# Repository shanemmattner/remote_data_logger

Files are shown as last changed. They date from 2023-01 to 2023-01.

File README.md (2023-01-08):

# Remote Data Logger
Remote data logger project for use in engineering development and debugging of electronics in the field

## Feature List

### Hardware
- ESP32-C3 circuit
- uart connection to target
- uSD card
- 16 GPIO

### Firmware
- ADC reading
- UART read/write
- Store values to uSD card
- Send values via WiFi

### Software
- Graph readings from ESP32-C3
- Talk with ESP32-C3 through Wi-Fi
- Talk with ESP32-C3 through UART

## Git
Update submodules manually:
```
git submodule update  --init --recursive
```

Configure repo to use custom `.githooks` path and make files executable:
```
git config --local core.hooksPath .githooks/
chmod -R +x .githooks
```

## KiCAD Hotkeys
- `e` while routing:  change parameters of trace
- `b` re-pour copper fills
    - `ctrl + b` to remove all fills
- `u` select entire track
- `v` via when routing
    - switch to bottom when not routing
- `c` Design rule check panel
    - custom hotkey

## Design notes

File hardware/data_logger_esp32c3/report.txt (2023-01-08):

Plotted to '/home/shane/Desktop/remote_data_logger/hardware/data_logger_esp32c3/gerbers/data_logger_esp32c3-F_Cu.gbr'.
Plotted to '/home/shane/Desktop/remote_data_logger/hardware/data_logger_esp32c3/gerbers/data_logger_esp32c3-In1_Cu.gbr'.
Plotted to '/home/shane/Desktop/remote_data_logger/hardware/data_logger_esp32c3/gerbers/data_logger_esp32c3-In2_Cu.gbr'.
Plotted to '/home/shane/Desktop/remote_data_logger/hardware/data_logger_esp32c3/gerbers/data_logger_esp32c3-B_Cu.gbr'.
Plotted to '/home/shane/Desktop/remote_data_logger/hardware/data_logger_esp32c3/gerbers/data_logger_esp32c3-F_Paste.gbr'.
Plotted to '/home/shane/Desktop/remote_data_logger/hardware/data_logger_esp32c3/gerbers/data_logger_esp32c3-B_Paste.gbr'.
Plotted to '/home/shane/Desktop/remote_data_logger/hardware/data_logger_esp32c3/gerbers/data_logger_esp32c3-F_Silkscreen.gbr'.
Plotted to '/home/shane/Desktop/remote_data_logger/hardware/data_logger_esp32c3/gerbers/data_logger_esp32c3-B_Silkscreen.gbr'.
Plotted to '/home/shane/Desktop/remote_data_logger/hardware/data_logger_esp32c3/gerbers/data_logger_esp32c3-F_Mask.gbr'.
Plotted to '/home/shane/Desktop/remote_data_logger/hardware/data_logger_esp32c3/gerbers/data_logger_esp32c3-B_Mask.gbr'.
Plotted to '/home/shane/Desktop/remote_data_logger/hardware/data_logger_esp32c3/gerbers/data_logger_esp32c3-Edge_Cuts.gbr'.
Created Gerber job file '/home/shane/Desktop/remote_data_logger/hardware/data_logger_esp32c3/gerbers/data_logger_esp32c3-job.gbrjob'.
Info: Done.

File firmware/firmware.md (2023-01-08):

# Firmware

Document to track firmware development

## Steps to set up a new ESP32 Rust project
1. [Install](https://github.com/esp-rs/rust-build) Rust and Xtensa build tools
    - Make sure to `sudo chmod +x export-esp.sh`
2. Start a project using the [esp-idf-template](https://github.com/esp-rs/esp-idf-template) from the private repo home `dir`. I chose all the default options
```
cargo generate --vcs none --git https://github.com/esp-rs/esp-idf-template cargo
```
3. Build the `Hello World` program by running `cargo build` in the new project dir. This will take a while to build the first time:
```
cd esp32-rust
cargo build
...
Finished dev [optimized + debuginfo] target(s) in 6m 40s
```
4. Flash the ESP32 with the build artifact:
```
espflash /dev/ttyACM0 target/riscv32imc-esp-espidf/debug/remote-data-logger
```
5. Connect to ESP32 and monitor
```
espmonitor /dev/ttyACM0
```

## TODO
- `Panic` if `pin 18/19` is reconfigured.  These pins are needed to download to the ESP32-C3 per [this](https://docs.espressif.com/projects/esp-idf/en/latest/esp32c3/api-guides/usb-serial-jtag-console.html) document

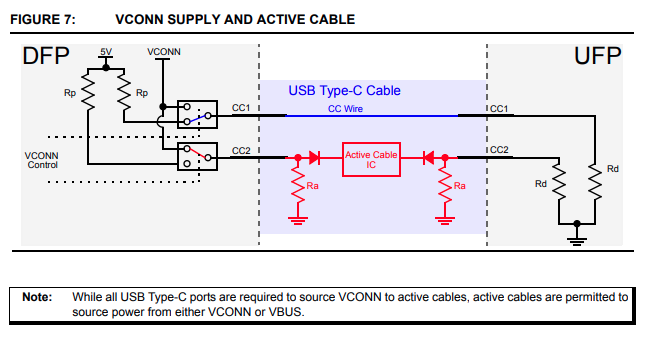
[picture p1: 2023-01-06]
pics/usbc_cc_pins.png

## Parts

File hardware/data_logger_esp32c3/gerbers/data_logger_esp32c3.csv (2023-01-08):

Id | Designator | Package | Quantity | Designation | Supplier and ref
1 | R18,R17 | R_0402_1005Metric | 2 | 30.1
2 | SDA1,SCL1,I2SP1,I2SN1,A4P1,A4N1,A3P1,A3N1,A2P1,A2N1,A0P1,A0N1,NRESET1,NINT1,IO13,DC-1,DC+1,IO11,IO5,VIN1,IO15,TX0,IO0,IO1,3V3,IO6,IO3,RX0,IO10,IO9,IO8,IO2,IO4,IO14,IO7,IO12 | TestPoint_THTPad_1.0x1.0mm_Drill0.5mm | 36 | TestPoint
3 | U5,U4,U8,U6,U7 | LM321MF | 5 | LM321MF
4 | R4,R1,R15,R3,R14,R9 | R_0402_1005Metric | 6 | 10k
5 | C1 | C_0402_1005Metric | 1 | 1uF
6 | R2,R7 | R_0402_1005Metric | 2 | 5.1k
7 | C2,C5,C4 | C_0603_1608Metric | 3 | 10uF
8 | SD1 | 472192001 | 1 | 472192001
9 | R12 | R_0402_1005Metric | 1 | 7.5k
10 | R6,R5,R13 | R_0402_1005Metric | 3 | 1k
11 | R16,R8 | R_0402_1005Metric | 2 | 4.7k
12 | U1 | ESP32-C3-MINI-1 | 1 | ESP32-C3-MINI-1
13 | R11 | R_0402_1005Metric | 1 | 3.92k
14 | R10 | R_0402_1005Metric | 1 | 1.6k
15 | U9,U10 | SOT-23 | 2 | A03401A
16 | D1 | DFN1610 | 1 | LTVS16H5.0T5G
17 | U2 | SOT-223-4 | 1 | AZ1117IH-3.3TRG1
18 | U11 | QFN-28-EP(4x4) | 1 | SX1509BIULTRT
19 | C3,C7,C6 | C_0402_1005Metric | 3 | 0.1uF
20 | USB-C1 | USB-TYPE-C-018 | 1 | USB-TYPE-C-018

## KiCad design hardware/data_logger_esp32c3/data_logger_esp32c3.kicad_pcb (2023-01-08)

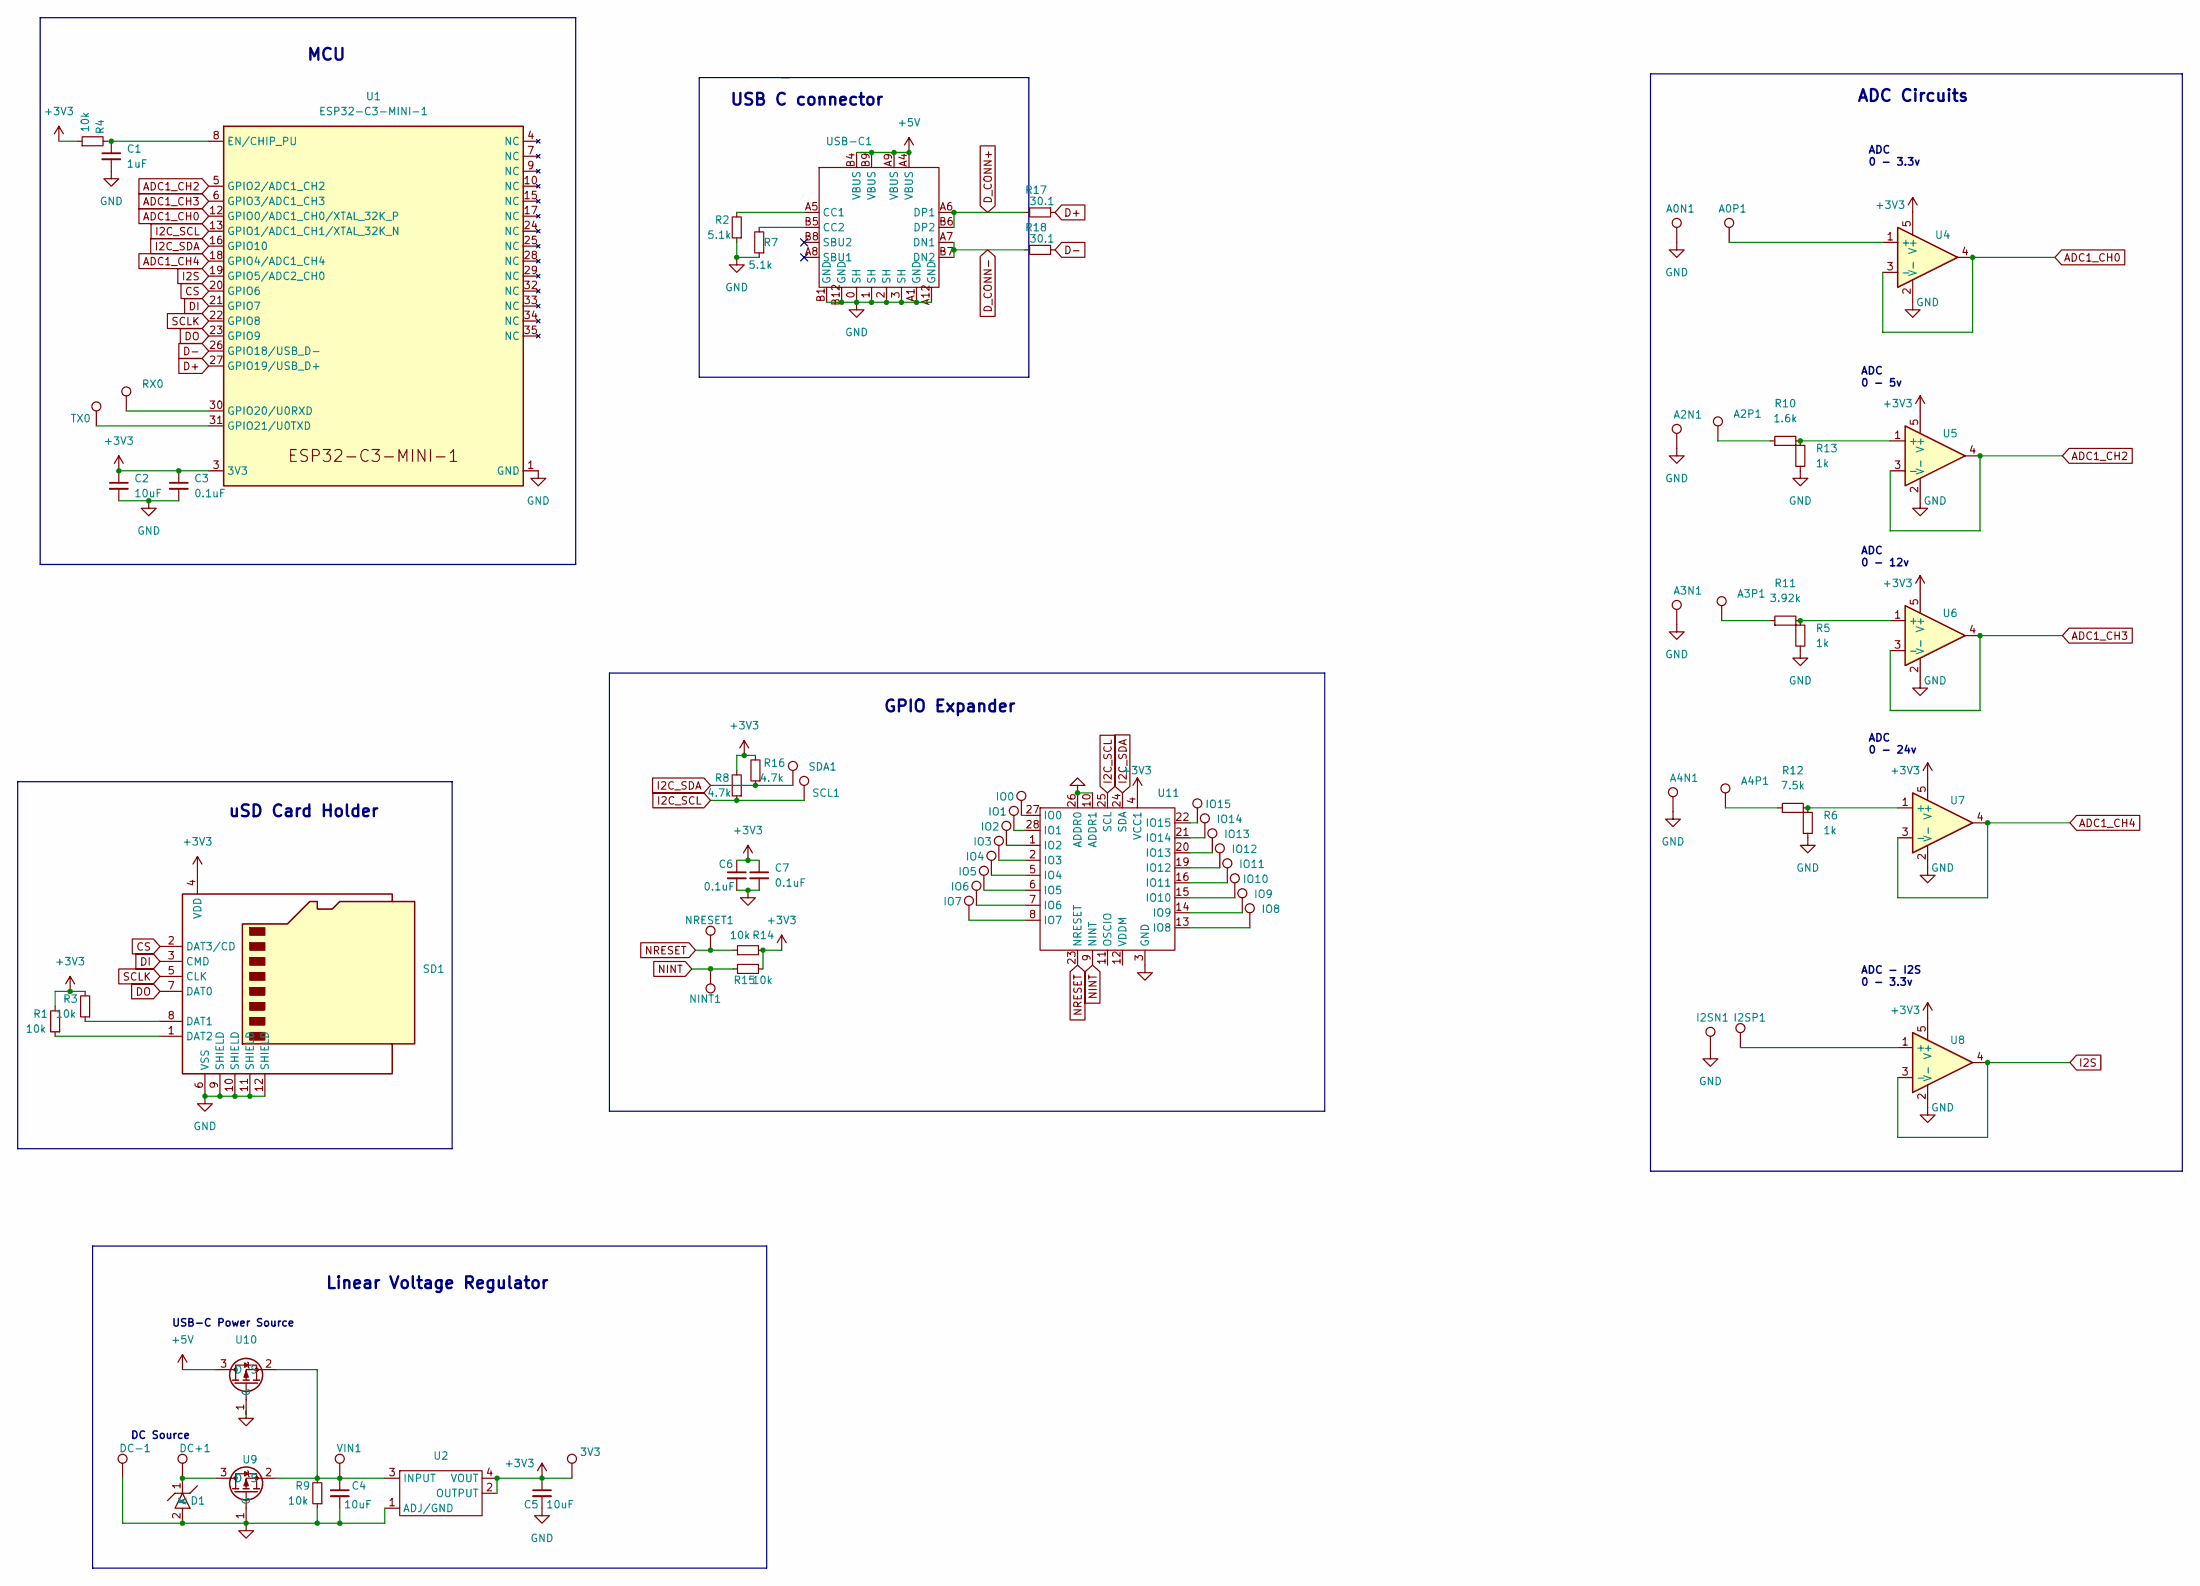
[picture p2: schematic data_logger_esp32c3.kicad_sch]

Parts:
3V3: TestPoint; TestPoint_THTPad_1.0x1.0mm_Drill0.5mm
A0N1, A0P1, A2N1, A2P1, A3N1, A3P1, A4N1, A4P1: TestPoint; TestPoint_THTPad_1.0x1.0mm_Drill0.5mm
C1: 1uF; C_0402_1005Metric; part_number 0402X105K6R3NT
C2, C4, C5: 10uF; C_0603_1608Metric; part_number CL10A106KO8NQNC
C3, C6, C7: 0.1uF; C_0402_1005Metric; part_number GCM155L81E104KE02D
D1: LTVS16H5.0T5G; DFN1610
DC+1: TestPoint; TestPoint_THTPad_1.0x1.0mm_Drill0.5mm
DC-1: TestPoint; TestPoint_THTPad_1.0x1.0mm_Drill0.5mm
I2SN1, I2SP1: TestPoint; TestPoint_THTPad_1.0x1.0mm_Drill0.5mm
IO0, IO1, IO2, IO3, IO4, IO5, IO6, IO7, IO8, IO9, IO10, IO11, IO12, IO13, IO14, IO15: TestPoint; TestPoint_THTPad_1.0x1.0mm_Drill0.5mm
NINT1: TestPoint; TestPoint_THTPad_1.0x1.0mm_Drill0.5mm
NRESET1: TestPoint; TestPoint_THTPad_1.0x1.0mm_Drill0.5mm
R1, R3, R4, R9, R14, R15: 10k; R_0402_1005Metric; part_number ERJ2RKF1002X
R2, R7: 5.1k; R_0402_1005Metric; part_number ERJ2RKF5101X
R5, R6, R13: 1k; R_0402_1005Metric; part_number CR-02FL6----1K
R8, R16: 4.7k; R_0402_1005Metric; part_number RC0402FR-074K7L
R10: 1.6k; R_0402_1005Metric; part_number RMC04021.6K1%N
R11: 3.92k; R_0402_1005Metric; part_number RC0402FR-073K9L
R12: 7.5k; R_0402_1005Metric; part_number AECR0402F7K50K9
R17, R18: 30.1; R_0402_1005Metric; part_number 0402WGF301JTCE
RX0: TestPoint; TestPoint_THTPad_1.0x1.0mm_Drill0.5mm
SCL1: TestPoint; TestPoint_THTPad_1.0x1.0mm_Drill0.5mm
SD1: 472192001; part_number 472192001
SDA1: TestPoint; TestPoint_THTPad_1.0x1.0mm_Drill0.5mm
TX0: TestPoint; TestPoint_THTPad_1.0x1.0mm_Drill0.5mm
U1: ESP32-C3-MINI-1
U2: AZ1117IH-3.3TRG1; SOT-223-4
U4, U5, U6, U7, U8: LM321MF; part_number LM321MF
U9, U10: A03401A; SOT-23
U11: SX1509BIULTRT; QFN-28-EP(4x4)
USB-C1: USB-TYPE-C-018
VIN1: TestPoint; TestPoint_THTPad_1.0x1.0mm_Drill0.5mm

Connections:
+3V3: 3V3.1, C2.1, C3.1, C5.1, C6.1, C7.1, R1.2, R3.2, R4.1, R8.2, R14.2, R15.2, R16.2, SD1.4 (VDD), U1.3 (3V3), U2.2 (OUTPUT), U2.4 (VOUT), U4.5 (V+), U5.5 (V+), U6.5 (V+), U7.5 (V+), U8.5 (V+), U11.4 (VCC1), U11.18 (VCC2)
+5V: U10.3 (D), USB-C1.A4 (VBUS), USB-C1.A9 (VBUS), USB-C1.B4 (VBUS), USB-C1.B9 (VBUS)
ADC1_CH0: U1.12 (GPIO0/ADC1_CH0/XTAL_32K_P), U4.3 (-), U4.4
ADC1_CH2: U1.5 (GPIO2/ADC1_CH2), U5.3 (-), U5.4
ADC1_CH3: U1.6 (GPIO3/ADC1_CH3), U6.3 (-), U6.4
ADC1_CH4: U1.18 (GPIO4/ADC1_CH4), U7.3 (-), U7.4
CS: SD1.2 (DAT3/CD), U1.20 (GPIO6)
D+: R17.1, U1.27 (GPIO19/USB_D+)
D-: R18.1, U1.26 (GPIO18/USB_D-)
DI: SD1.3 (CMD), U1.21 (GPIO7)
DO: SD1.7 (DAT0), U1.23 (GPIO9)
D_CONN+: R17.2, USB-C1.A6 (DP1), USB-C1.B6 (DP2)
D_CONN-: R18.2, USB-C1.A7 (DN1), USB-C1.B7 (DN2)
GND: A0N1.1, A2N1.1, A3N1.1, A4N1.1, C1.2, C2.2, C3.2, C4.2, C5.2, C6.2, C7.2, D1.2 (A), DC-1.1, I2SN1.1, R2.1, R5.2, R6.2, R7.1, R9.1, R13.2, SD1.6 (VSS), SD1.9 (SHIELD), SD1.10 (SHIELD), SD1.11 (SHIELD), SD1.12 (SHIELD), U1.1 (GND), U1.2 (GND), U1.11, U1.14, U1.36 (GND), U1.37 (GND), U1.38 (GND), U1.39 (GND), U1.40 (GND), U1.41 (GND), U1.42 (GND), U1.43 (GND), U1.44 (GND), U1.45 (GND), U1.46 (GND), U1.47 (GND), U1.48 (GND), U1.49 (GND), U1.50 (GND), U1.51 (GND), U1.52 (GND), U1.53 (GND), U2.1 (ADJ/GND), U4.2 (V-), U5.2 (V-), U6.2 (V-), U7.2 (V-), U8.2 (V-), U9.1 (G), U10.1 (G), U11.3 (GND), U11.10 (ADDR1), U11.17 (GND), U11.26 (ADDR0), U11.29 (PAD), USB-C1.0 (SH), USB-C1.1 (SH), USB-C1.2 (SH), USB-C1.3 (SH), USB-C1.A1 (GND), USB-C1.A12 (GND), USB-C1.B1 (GND), USB-C1.B12 (GND)
I2C_SCL: R8.1, SCL1.1, U1.13 (GPIO1/ADC1_CH1/XTAL_32K_N), U11.25 (SCL)
I2C_SDA: R16.1, SDA1.1, U1.16 (GPIO10), U11.24 (SDA)
I2S: U1.19 (GPIO5/ADC2_CH0), U8.3 (-), U8.4
NINT: NINT1.1, R15.1, U11.9 (NINT)
NRESET: NRESET1.1, R14.1, U11.23 (NRESET)
unnamed: A0P1.1, U4.1 (+)
unnamed: A2P1.1, R10.1
unnamed: A3P1.1, R11.1
unnamed: A4P1.1, R12.1
unnamed: C1.1, R4.2, U1.8 (EN/CHIP_PU)
unnamed: C4.1, R9.2, U2.3 (INPUT), U9.2 (S), U10.2 (S), VIN1.1
unnamed: D1.1 (K), DC+1.1, U9.3 (D)
unnamed: I2SP1.1, U8.1 (+)
unnamed: IO0.1, U11.27 (IO0)
unnamed: IO1.1, U11.28 (IO1)
unnamed: IO2.1, U11.1 (IO2)
unnamed: IO3.1, U11.2 (IO3)
unnamed: IO4.1, U11.5 (IO4)
unnamed: IO5.1, U11.6 (IO5)
unnamed: IO6.1, U11.7 (IO6)
unnamed: IO7.1, U11.8 (IO7)
unnamed: IO8.1, U11.13 (IO8)
unnamed: IO9.1, U11.14 (IO9)
unnamed: IO10.1, U11.15 (IO10)
unnamed: IO11.1, U11.16 (IO11)
unnamed: IO12.1, U11.19 (IO12)
unnamed: IO13.1, U11.20 (IO13)
unnamed: IO14.1, U11.21 (IO14)
unnamed: IO15.1, U11.22 (IO15)
unnamed: R1.1, SD1.1 (DAT2)
unnamed: R2.2, USB-C1.A5 (CC1)
unnamed: R3.1, SD1.8 (DAT1)
unnamed: R7.2, USB-C1.B5 (CC2)
unnamed: R10.2, R13.1, U5.1 (+)
unnamed: R5.1, R11.2, U6.1 (+)
unnamed: R6.1, R12.2, U7.1 (+)
unnamed: RX0.1, U1.30 (GPIO20/U0RXD)
unnamed: TX0.1, U1.31 (GPIO21/U0TXD)
SCLK: SD1.5 (CLK), U1.22 (GPIO8)

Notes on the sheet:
ADC Circuits
uSD Card Holder
Linear Voltage Regulator
ADC 0 - 5v
USB-C Power Source
ADC 0 - 3.3v
ADC 0 - 12v
DC Source
USB C connector
GPIO Expander
MCU
ADC 0 - 24v
ADC - I2S 0 - 3.3v

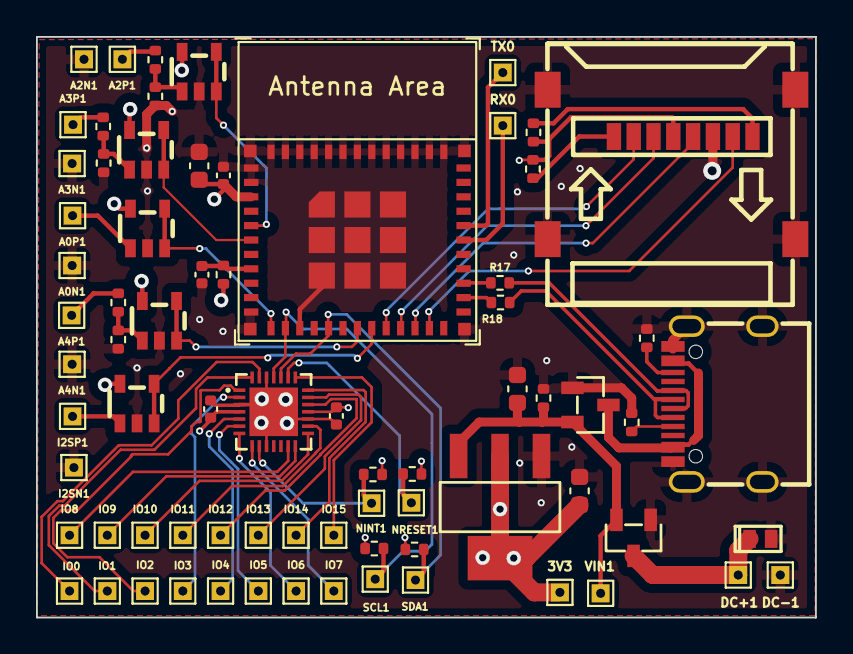
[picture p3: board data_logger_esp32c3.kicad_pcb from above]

Board: 4 copper layers, 43.3 x 32.3 mm, 74 parts (0 on the bottom side), 53 nets.

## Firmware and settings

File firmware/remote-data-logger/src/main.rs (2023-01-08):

use esp_idf_sys as _; // If using the `binstart` feature of `esp-idf-sys`, always keep this module imported

use esp_idf_hal::i2c;
use esp_idf_hal::prelude::*;
use std::thread;
use std::time::Duration;
use sx1509;

fn main() {
    // It is necessary to call this function once. Otherwise some patches to the runtime
    // implemented by esp-idf-sys might not link properly. See https://github.com/esp-rs/esp-idf-template/issues/71
    esp_idf_sys::link_patches();

    let p = Peripherals::take().unwrap();
    // I2C
    let sda = p.pins.gpio1.into_input_output().unwrap();
    let scl = p.pins.gpio10.into_output().unwrap();
    let config = <i2c::config::MasterConfig as Default>::default().baudrate(400.kHz().into());
    let mut i2c1 =
        i2c::Master::<i2c::I2C0, _, _>::new(p.i2c0, i2c::MasterPins { sda, scl }, config).unwrap();

    // GPIO expander
    let mut expander = sx1509::Sx1509::new(&mut i2c1, sx1509::DEFAULT_ADDRESS);
    expander.borrow(&mut i2c1).software_reset().unwrap();
    expander.borrow(&mut i2c1).set_bank_a_direction(0).unwrap();
    expander
        .borrow(&mut i2c1)
        .set_bank_b_direction(0xFF)
        .unwrap();
    expander.borrow(&mut i2c1).set_bank_a_pullup(0xFF).unwrap();

    // MAIN LOOP
    loop {
        thread::sleep(Duration::from_millis(100));

        let buff = expander.borrow(&mut i2c1).get_bank_a_data().unwrap();

        println!("buff: {}", buff);
        thread::sleep(Duration::from_millis(100));
    }
}

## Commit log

2022-12-04 making hardware circuits
    [data_logger_esp32c3.kicad_pcb, data_logger_esp32c3.kicad_sch]
2022-12-04 remove backups
    [data_logger_esp32c3.kicad_sch]
2022-12-04 add connector
    [data_logger_esp32c3.kicad_pcb, data_logger_esp32c3.kicad_sch]
2022-12-04 add submodule for connector
2022-12-04 Added regulator circuit
    [data_logger_esp32c3.kicad_pcb, data_logger_esp32c3.kicad_sch]
2022-12-05 JLCPCB assembly compliant
2022-12-05 Added uSD circuit
    [adc_circuit.kicad_sch, data_logger_esp32c3.kicad_pcb, data_logger_esp32c3.kicad_sch]
2022-12-05 laying out board
    [data_logger_esp32c3.kicad_pcb]
2022-12-05 last commit of the night
    [data_logger_esp32c3.kicad_pcb, data_logger_esp32c3.kicad_sch]
2023-01-06 Added relative path libraries for kicad
    [data_logger_esp32c3.kicad_sch]
2023-01-07 added linear regulator, changed to 0402 passives
    [data_logger_esp32c3.kicad_pcb, data_logger_esp32c3.kicad_sch]
2023-01-07 Adding to pcb
    [adc_circuit.kicad_sch, data_logger_esp32c3.kicad_pcb, data_logger_esp32c3.kicad_sch]
2023-01-07 More hardware work
    [data_logger_esp32c3.kicad_pcb, data_logger_esp32c3.kicad_sch]
2023-01-07 adding to hardware
    [data_logger_esp32c3.kicad_pcb, data_logger_esp32c3.kicad_sch]
2023-01-08 Add gpio expander. Layout complete
    [data_logger_esp32c3.kicad_pcb, data_logger_esp32c3.kicad_sch]
2023-01-08 Edit schematic
    [data_logger_esp32c3.kicad_sch]
2023-01-08 more layout
    [data_logger_esp32c3.kicad_pcb, data_logger_esp32c3.kicad_sch]
2023-01-08 commit before routing
    [data_logger_esp32c3.kicad_pcb, data_logger_esp32c3.kicad_sch]
2023-01-08 added copper fills
    [data_logger_esp32c3.kicad_pcb]
2023-01-08 routing done
    [data_logger_esp32c3.kicad_pcb, data_logger_esp32c3.kicad_sch]
2023-01-08 last commit for the night
    [data_logger_esp32c3-B_Cu.gbr, data_logger_esp32c3-B_Mask.gbr, data_logger_esp32c3-B_Paste.gbr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]
